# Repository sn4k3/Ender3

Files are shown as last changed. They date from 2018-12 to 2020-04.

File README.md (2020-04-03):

# Ender3
Supercharge your Ender3 with Guides, Mods and Addons.
Make your Ender3 work and worth like high end machines.

**Note:** I have spend many hours trying put this together so you can supercharge your Ender-3 for "Free", if my work is important to you or you fell this worth a tip i'm open to donations: https://www.paypal.me/SkillTournament

Discussion Groups:
* https://www.facebook.com/groups/Ender3/

## 1. PrusaSlicer

These profiles are based on a quality/speed balance (Universal).
Good prints without sacrifice the speed.
Make sure you have a good leveled printer and bed.

**NOTE:** Fine tune the start gcode for your printer! This is very important since i can't provide a all case profile for every modification and printer.

Modify at your needs.

### 1.1. Instalation
1. Download and install PrusaSlicer from: https://www.prusa3d.com/prusaslicer/
2. Start and configure PrusaSlicer (Wizard)
	* Choose Prusa MK3 and Creality Ender3 printers
	* Choose the filaments you want to apper (This can be latter done under Filament dropdown and select "Add/Remove Materials")
3. Close PrusaSlicer
4. On different operating systems open:
   * Windows: "%AppData%\PrusaSlicer\"
   * macOS: "/Users/[Username]/Library/Application Support/PrusaSlicer"
   * Linux: 
      * Stable build: "~/.PrusaSlicer/"
      * Alpha build: "~/.PrusaSlicer-alpha/"
5. Copy GitHub PrusaSlicer subfolders ("printer", "filament", "print") to the folder above
7. Open PrusaSlicer and check if profiles are there
8. To clean up interface remove profiles that you will not use: Printers you will not use (OPTIONAL)
9. Go under printer and use your current values for your printer, like max Z, limits, start gcodes or other things you may need to tune
10. Do a simple test print

## 2. Hardware

### 2.1. Best parts store:

* **Trianglelab:** https://trianglelab.aliexpress.com/store/1654223
* **Funssor:** https://www.aliexpress.com/store/115344

### 2.2. Recommended Hardware:

**Note:** Somes parts can override others! Study first what you want or need to buy.

* Cloned Bondtech BMG extruder for direct drive or better bowden: https://www.aliexpress.com/store/product/trianglelab-Bowden-Extruder-BMG-extruder-Cloned-Btech-Dual-Drive-Extruder-for-3d-printer-High-performance-for/1654223_329170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
* V6+Volcano 1.75mm 24V: https://www.aliexpress.com/store/product/Trianglelab-v6-Volcano-hotend-12V-24V-remote-Bowen-print-J-head-Hotend-and-cooling-fan-bracket/1654223_32844080369.html
* Volcano Nozzles (1.75 Full Size Kit): https://www.aliexpress.com/store/product/trianglelab-Top-quality-V6-volcano-Nozzle-for-3D-printers-hotend-5pcs-lot-volcano-upgrade-kit-for/1654223_32839344108.html
* Volcano Sock: https://www.aliexpress.com/item/Funssor-1pcs-Volcano-Heater-Block-Silicone-Socks-PT100-cartridge-Type-Silicone-Insulation-Sock-SILICONE-HEATER-BLOCK/32841090475.html
* Extruder gear: https://www.aliexpress.com/store/product/trianglelab-Drivegear-kit-dual-drive-gear-extruder-kit-Cloned-Btech-upgrade-for-Prusa-i3-3d-printer/1654223_32904209624.html
* MK8 Metal Extruder: https://www.aliexpress.com/item/Upgrade-3D-Printer-Parts-MK8-Extruder-Aluminum-Alloy-Block-bowden-extruder-1-75mm-Filament-for-creality/32834380573.html
* 3D Touch: https://www.aliexpress.com/store/product/Trianglelab-2018-NEW-3D-Printer-3D-TOUCH-SENSOR-Free-Shipping-Auto-BED-Leveling-Sensor-for-anet/1654223_32840691571.html
* BLTouch board adaptor: https://www.ebay.co.uk/itm/CR-10-Ender-3-Pin-27-Board-for-BL-Touch-Autobed-Levelling-or-filament-sensor/173475394925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
* TL Smoother Plus: https://www.aliexpress.com/store/product/Trianglelab-4-pieces-pack-TL-smoother-PLUS-addon-module-for-3D-pinter-motor-drivers-motor-Driver/1654223_32841473812.html
* NEMA 17 Dampers: https://www.aliexpress.com/item/Funssor-12pcs-lot-NEMA-17-Steel-Rubber-Stepper-Motor-Vibration-Dampers-Imported-genuine-42-stepper-motor/32825669027.html
* Official Glass Bed Surface: https://www.aliexpress.com/item/Newest-Creality-3D-Printer-Ender-3-Black-Carbon-Silicon-Crystal-Glass-Platform-Build-Hotbed-Glass-Platform/32890715441.html
* Bed Springs (4x): https://www.aliexpress.com/item/4-pcs-CREALITY-3D-Printer-Parts-Spring-For-Heated-bed-CR-10-CR-10Mini-CR-10S/32864621140.html
* Bed Isolator (300x300): https://www.aliexpress.com/item/3D-Printer-Part-Heated-Bed-Thermal-Insulator-Cotton-Heat-Insulation-Mat-for-Heatbed-Aluminum-Pad-PCB/32879628172.html
* 5015 24v Fan: https://www.aliexpress.com/item/2PCS-Gdstime-2-Pin-Ball-Bearing-DC-24V-Brushless-Cooling-Turbine-Blower-Fan-5015/32841967974.html
* 4010 24v Fan: https://www.aliexpress.com/item/2Pcs-DC-24V-40mm-x-40mm-x-10mm-2-Pin-Ball-Bearing-Computer-PC-Case-Silent/32727867521.html
* Fan speed controler: https://www.aliexpress.com/item/10pcs-lot-PWM-DC-6V-12V-24V-28V-3A-Motor-Speed-Control-New-Switch-Controller-1203B/32714571858.html
* Extreme v wheels (16x): https://www.aliexpress.com/item/High-precision-CNC-clear-Polycarbonate-Xtreme-v-wheel-kits-for-Openbuilds-v-slot-linear-rail-system/32849105844.html
* Belt Tensioner: https://www.aliexpress.com/store/product/Funssor-upgrade-Aluminum-alloy-Tornado-CR-10S-X-Axis-Tensioner-kit-For-Creality-cr-10-Ender/115344_32882354827.html
* XT30 Connectors: https://www.aliexpress.com/item/10pcs-Amass-XT30-Male-Female-Bullet-Connector-Plug-For-RC-FPV-Lipo-Battery-RC-Quadcopter-5/32784217001.html
* Arduino Uno for Stock motherboard bootloader burn: https://www.aliexpress.com/item/high-quality-One-set-UNO-R3-CH340G-MEGA328P-for-Arduino-UNO-R3-NO-USB-CABLE/32697443734.html
* Raspberry Pi 3+ with Octoprint and PiCamera

## 3. Printed Parts

### 3.1. Colections

* **sn4k3** https://www.thingiverse.com/sn4k3/collections/creality-ender-3
* **Nerys** https://www.thingiverse.com/Nerys/collections/ender-3

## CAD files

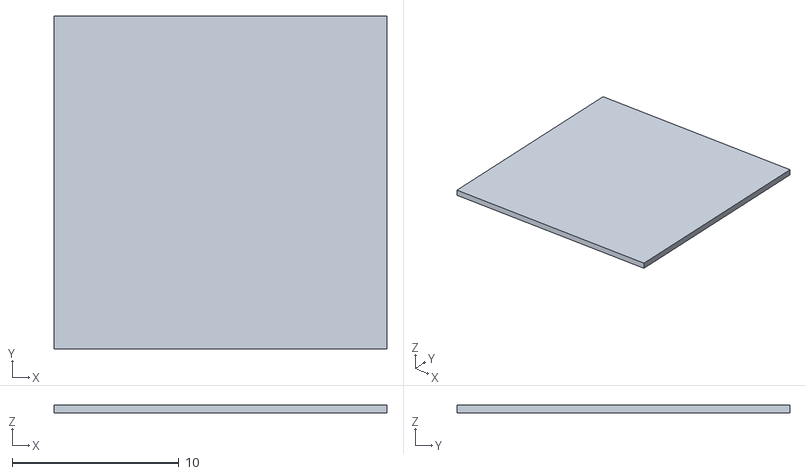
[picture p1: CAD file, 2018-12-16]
TestSTLs/2Layer20x203um.stl
20.0 x 20.0 x 0.5

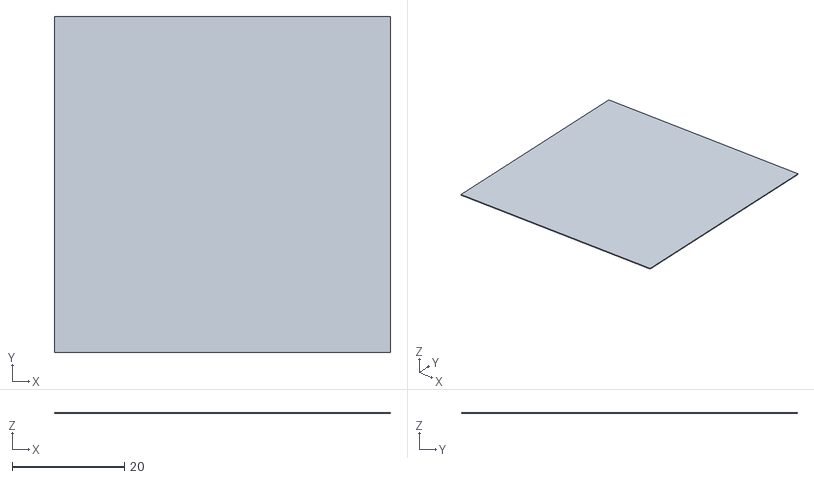
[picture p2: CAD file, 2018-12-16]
TestSTLs/1Layer60x60.stl
60.0 x 60.0 x 0.2

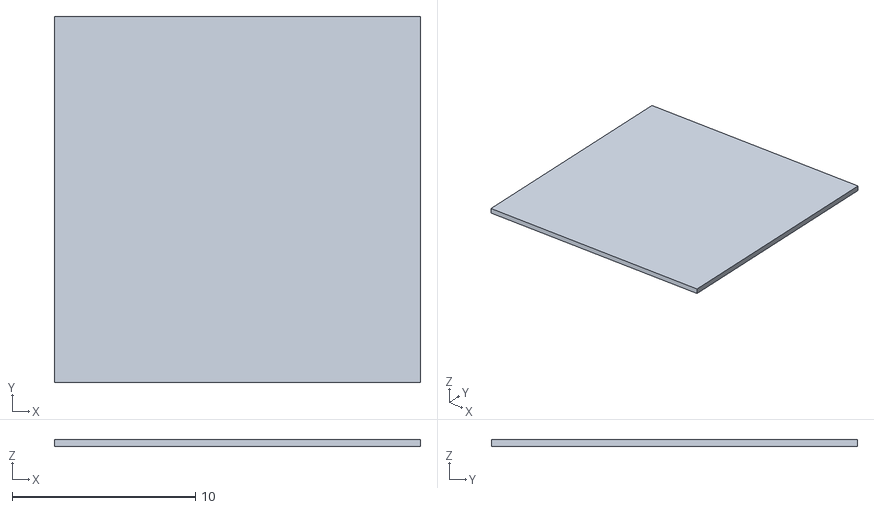
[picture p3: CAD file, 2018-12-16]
TestSTLs/2Layer20x20.stl
20.0 x 20.0 x 0.4

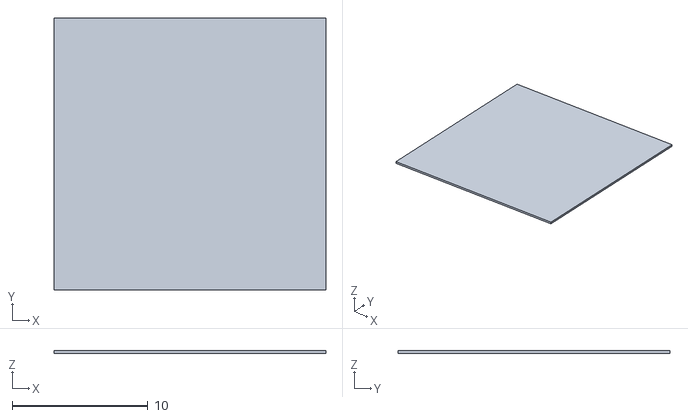
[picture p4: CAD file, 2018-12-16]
TestSTLs/1Layer20x20.stl
20.0 x 20.0 x 0.2

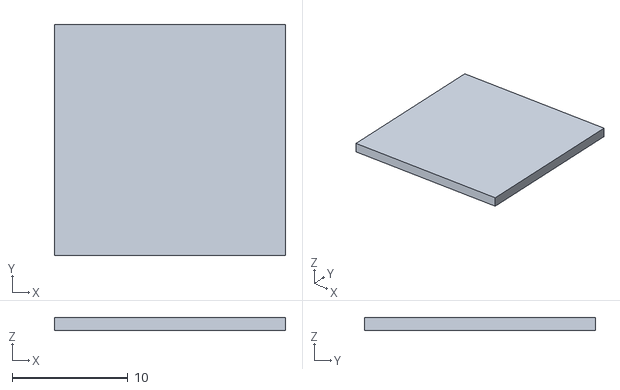
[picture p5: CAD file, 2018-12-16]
TestSTLs/6Layer20x20.stl
20.0 x 20.0 x 1.10

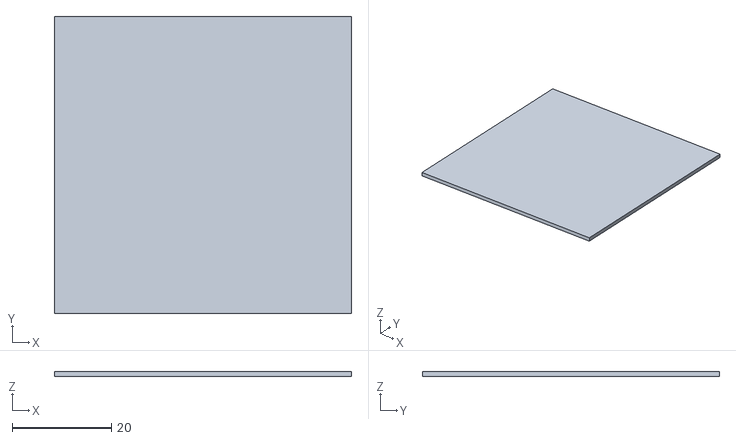
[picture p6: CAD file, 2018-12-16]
TestSTLs/6Layer60x60.stl
60.0 x 60.0 x 1.10

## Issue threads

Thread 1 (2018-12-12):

Error exporting gcode

XabierV, 2018-12-12:
Using printer Creality Ender3 - Stock, filament Generic PLA, and print 0.20mm Normal Ender3 with Slic3rPE 1.39.0, with 3DBenchy STL. Slice process completes correctly, but fails to export the gcode file, with the following error message:

!!!!! Failed to process the custom G-code template end_gcode
Parsing error at line 9: Not a variable name
{if layer_z < max_print_height}G1 Z{z_offset+min(layer_z+30, max_print_height)}{endif} ; Move print head up
    ^
!!!!! End of an error report for the custom G-code template end_gcode

I'm a total newbie with 3D printing and slicing, but it looks as the variable layer_z is not being initialized...

[3DBenchy_PLA0.2mm.gcode.txt](https://github.com/sn4k3/Ender3/files/2673063/3DBenchy_PLA0.2mm.gcode.txt)

sn4k3, 2018-12-12:
You need to download the new Slic3r PE, the 1.39 don't have that option... Please update

Closed 2018-12-12.

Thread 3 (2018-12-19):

Compatible printer strings?

talldonkey, 2018-12-19:
Hi - Thank you for keeping this up to date.

I was curious about your latest commit so I took a look at the diff and noticed that there's some mentions of Prusa where I think creality and ender 3 was intended, see below examples.

`compatible_printers_condition = printer_notes=~/.*PRINTER_VENDOR_PRUSA3D.*/ and printer_notes=~/.*PRINTER_MODEL_MK3.*/ and printer_notes=~/.*PRINTER_HAS_VOLCANO.*/ and nozzle_diameter[0]==0.6`

When I was expecting to see Creality instead of Prusa.  The *theoretical* effect would that these profiles would not show up when the Ender-3 is selected (I haven't tested it out for myself)

`compatible_printers_condition = printer_notes=~/.*PRINTER_VENDOR_CREALITY.*/ and printer_notes=~/.*PRINTER_MODEL_ENDER3.*/ and nozzle_diameter[0]==0.8 and printer_notes=~/.*PRINTER_HAS_VOLCANO.*/
`
I see this in mostly the new 0.6 nozzle files.

Was this intentional, (maybe I'm misunderstanding the reason why Prusa is in there)

sn4k3, 2018-12-19:
Hello,

The reason why i put that is because i have i have both MK3 and Ender 3 with same config (Direct Drive + Volcano + E3D) So to avoid edit two times the profiles i had put that to allow me share the profile on MK3 and Ender3, if you look at printer (Creality DD) you can find that:

Don't remove the following keywords! These keywords are used in the "compatible printer" condition of the print and filament profiles to link the particular print and filament profiles to this printer profile.
PRINTER_VENDOR_CREALITY
PRINTER_MODEL_ENDER3
PRINTER_HAS_VOLCANO
PRINTER_HAS_DIRECT_DRIVE
PRINTER_VENDOR_PRUSA3D
PRINTER_MODEL_MK3
MAX_VOLUMETRIC_25
MAX_SPEED_85

So in end is just to easy my life, and yes if you have Prusa MK3 you can use that too.
To convert in bowden you just need to change Printer Tab config.

Also i can't support every possible config, so take one and modify at your will, my start gcode would not work very well for the commun pleople since i have tons of mods include linear rails, so never forget to test and adjust printer tab!! All settings i have are tested by me when i use printer in that configuration.

Regards

talldonkey, 2018-12-21:
Hi, Ah - now that make sense now.  Great.  I also happen to have a MK3 Also
so this repo would be even more useful now!

Another question - you have BLTouch, and BLTouch Recall.  What's the Recall
version for?  I don't have a Bltouch but an EZABL, and would need to modify
the start codes, but wondering what it is - googling for "BLTouch Recall"
doesn't help much

On Tue, Dec 18, 2018 at 5:35 PM Tiago Conceição <notifications@github.com>
wrote:

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

sn4k3, 2018-12-21:
Yes recall is a name i gave myself, mean it will not run mesh bed but load it from last run values stored on EEPROM instead, so it's Recall ^^ and saves time, but last values must be there and ok (bed same level).
It work will ABL too but i recommend to run every time since ABL is faster than bltouch to probe i think...

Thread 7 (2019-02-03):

ColorMe3D PETG settings

NovaViper, 2019-02-03:
Hey guys! I'm very new to Slic3r and I would like to know if you guys could create a profile for the ColorMe3D PETG filaments, such as the ones I currently have below:

https://www.amazon.com/gp/product/B07L5V9LP7/ref=ppx_yo_dt_b_asin_title_o03__o00_s00?ie=UTF8&psc=1

https://www.amazon.com/gp/product/B07LB6RXDR/ref=ppx_yo_dt_b_asin_title_o02__o00_s00?ie=UTF8&psc=1

I would really appreciate the addition :D

sn4k3, 2019-02-03:
Do a blind profile will be inaccurate. Best is try with the real thing.
They say Hotend 235 and BED TEMP at 30, PETG need more temperature to bed to stick well so i recommend you try higher value like GENERIC PETG profile or from 70 to 90ºc.
After do can do a temperature tower from 210 to 240ºc and see which is better.
With that you will have your profile correct.
PS: Duplicate PETG profile and fine tune it

Closed 2019-02-03.

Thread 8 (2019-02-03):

Intro priming line collides with paper clips

probonopd, 2019-02-03:
The intro priming line collides with where most people would normally put their paper clips for attaching the flexible plate that comes with the later revisions of the Ender 3.

Hence, the intro priming line should be moved e.g., to the side, where no paper clips are usually installed.

sn4k3, 2019-02-03:
The profiles provide a base for users, the start gcode must be tuned by the user itself, since Ender3 is heavy modded i can't provide every case-of-use profile. The prime line is based on stock Ender3 (without ultrabase). BTW i also have a custom base and i hate clips because of that and smaller area, so i use Kypton tape all arround +/- 5mm edge. Have hard objects under nozzle area is always a bad idea

sn4k3, 2019-02-04:
I can do that latter. But you can see my 0.6mm DD profile which have prime line that way and replace the gcode for your profile. You can also send a pull request with that mod

sn4k3, 2019-02-08:
Change prime to Y on new release

probonopd, 2019-02-08:
Thanks. :+1:

Closed 2019-02-08.

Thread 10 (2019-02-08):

Under extrusion on small cylinders with possible fix.

abrileroux, 2019-02-08:
Hi there,
First of all thank you very much for the profiles for the ender 3. I'm getting the best prints I've ever had with your profiles.

I ran into an issue where the whole print would work beautifully until I got to a small cylinder/chimney shape. The printer would under-extrude badly for that shape resulting in a failure. The same file would print fine when sliced with Cura.

[Pictures](https://imgur.com/a/LZ0PhBn)

The solution I found was to remove the following line from the start Gcode :

`M221 S{if layer_height<0.075}100{else}95{endif}`

It seems that the flow rate of 95 was just low enough to fail.
A flow rate of 100 doesn't cause any problems with the print, so I haven't noticed a downside to removing it (yet).

Just wanted to share my finding. Thank you again!

yarus23, 2019-02-08:
95 is too low for quality supports that are printed with higher speed. So 100% is the best value

sn4k3, 2019-02-08:
95 was the best value i found after tune e-steps. Are your e-steps extruding 100mm out of 100mm?
My ender3 come with esteps a bit off so i tunned first and 100% at slice gave me overextrusion, that's why i set it to 95.
Please tell me about your e-steps value

abrileroux, 2019-02-08:
> Please tell me about your e-steps value

Hi there, sure. My E-steps is at 100.4.

Thanks

sn4k3, 2019-02-08:
Humm a bit higher then my was. My was 98 for get perfect 100mm out of 100mm PLA

sn4k3, 2019-02-08:
Ajustment removed

Closed 2019-02-08.

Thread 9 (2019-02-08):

Adjust Z position

yarus23, 2019-02-08:
I have to insert
G28 Z
before G1 Z0.6 because we need to go home by Z axis before printing, otherwise it prints in the air

abrileroux, 2019-02-08:
Thanks for that - I also have this issue

sn4k3, 2019-02-08:
Confirmed, G28; missing before print starts, i will fix soon

sn4k3, 2019-02-08:
Fixed on new release

Closed 2019-02-08.

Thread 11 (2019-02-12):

Under/no extrusion while after priming phase

NovaViper, 2019-02-12:
For some strange reason, I notice that the printer doesn't seem to be extruding at all, which has been causing me **lots** of headache trying to figure out why.

sn4k3, 2019-02-12:
Which printer profile are you using?
Can you try manual extrusion via printer menu and see if it extrudes at all?

NovaViper, 2019-02-24:
I think it's my e-steps not being calibrated. I'm going to go and try to calibrate them sometime Friday and *hopefully* get the issue fixed

sn4k3, 2019-02-24:
I had that problem before and was e-steps

Closed 2019-02-24.

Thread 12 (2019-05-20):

Question: Does the jerky-zick-zack move work in practice?

talldonkey, 2019-05-20:
Hi, just wondering how useful you find the jerky zick zack move.  I notice that you have it commented out (or its not there) on some profiles, especially Ender-3 BLtouch printer profile.

G91 ; Use relative mode
; Make some jerky zick-zack move at the beginning
; This is supposed to get rid of residue at the nozzle
;G1 X1.0 Y5.0 Z-0.1 E-1.0 F7200 ; X6 Y10 Z0.1, retract a tiny bit / 120mm/s
;G1 X1.0 Y-5.0 Z0.1 E2.0 F7200 ; X7 Y5 Z0.2 extrude a tiny bit
;G1 X2.0 Y5.0 Z-0.1 F7200 ; X9 Y10 Z0.1
;G1 X2.0 Y-5.0 Z0.1 F7200 ; X11 Y5 Z0.2
;G1 X2.0 Y5.0 F7200 ; X13 Y10
;G1 X2.0 Y-5.0 F7200 ; X15 Y5

sn4k3, 2019-05-20:
Hello, It's disable on other for safety, if nozzle goes under bed it can crash and make damage somewhere.
It's not very usefull since it need be very close from bed, and i can't provide that on universal profiles.
The purge line is ok.
It would be more usefull if your printer had a cleaning zone with brushes or something to clean nozzle.

Closed 2019-05-24.

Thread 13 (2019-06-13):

Filament priming

sfjuocekr, 2019-06-13:
The feed rate during the priming strip is a little high.

The first part comes out okay, but during the second part the extruder gear slips and if your coupling like mine is a little wonkey it will slide out as it is the weakest link after the extruder gear.

Personally, I don't think overextruding with force is required to prime the nozzle.

sfjuocekr, 2019-06-13:
Also, the start gcode differs between the profiles. I think you forgot to update the others, for example stock still has the jerky zig zag!

sn4k3, 2019-06-13:
The printer tab must be configured to the user preference and needs.
What printer setting you are using?

sfjuocekr, 2019-06-18:
Ender-3

If you do a diff on the stock profile vs one of the recently changed ones and grep out the start gcode line you will notice the differences.

sn4k3, 2019-06-18:
You mean Ender3 Stock? I know stock are different from others in prime.
I don't have stock anymore to test and try, my bed is also different coordinates and size.
On installation change printer tab and tune to your preference is required and a step of instalation, i can't cover a all in one profile as ender3 is the most hacked printer. When i used the stock profile in the past my extruder never click or skip steps at prime.
But if you can fix it, test and send gcode back, i will update the default for stock and bltouch which have same prime

Closed 2019-07-13.

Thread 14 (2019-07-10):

this is not an issue.. just a question

phamre, 2019-07-10:
Hello..

i like your work.. thanks

i have direct drive setup with v6 hotend and bmg extruder..
u think i can use your volcano direct drive profile?
im not sure what differance between v6 and volcano hotend

Thanks again

sn4k3, 2019-07-10:
Sure you can use. Just go printer tab and remove volcano from comments. OR reduce max speeds by half at all infills

DAddYE, 2019-07-24:
What exact setup are you using? I’m same as OP but I’ve a 0.6 volcano nozzle. Can I use volcano profiles?

I’m also wondering if i change to a 0.4 nozzle should I change all values in the Extruder setting as well... right?

Lastly, what’s the difference with bl touch and the one with recall?

Thanks mate!

NovaViper, 2019-07-24:
@DAddYE The recall one basically is the same like the regular bltouch one with the exception that it loads the mesh data that you set before (and not probe the bed before each print) while the regular bltouch profile *always* probe the bed before starting the print

sn4k3, 2019-07-24:
> What exact setup are you using? I’m same as OP but I’ve a 0.6 volcano nozzle. Can I use volcano profiles?

I'm using 0.6mm Volcano DD (Direct Drive)
You can and should use it, but if you have bowden you need to change two parameters only (retraction is all you need to change in fact)

> I’m also wondering if i change to a 0.4 nozzle should I change all values in the Extruder setting as well... right?
>

If so you need to recreate profiles and printer, mostly you will only incrase infills speeds but only up to a safe margin which i set to be +/- 150mm/s

> Lastly, what’s the difference with bl touch and the one with recall?
>
> Thanks mate!

Already anwsered

DAddYE, 2019-07-25:
Thanks mate! I got this:

MK8 Bowden Extruder BMG extruder + V6 HOTEND Dual Drive Extruder for 3D Printer High Performance for I3 3D Printer - (Size: BMG 24V All-Metal) https://www.amazon.com/dp/B07KVHG5FH/ref=cm_sw_r_cp_api_i_nOsoDbTB4YVFN

I’m on direct drive but I have a v6 hot end.

phamre, 2019-07-29:
> Sure you can use. Just go printer tab and remove volcano from comments. OR reduce max speeds by half at all infills

i dont understand what comments i need to remove.. and when i change Directdrive profile and save with a new name.. all printer profiles so are not there longer..

maby you can take a screenshot and show what i need to do?

sn4k3, 2019-07-29:
@phamre tell me your setup (noozle size, volcano or v6, Bowden or direct, bed probe)

DAddYE, 2019-07-30:
The volcano option, AFAIK, only enables specific filament profiles.

Do the options in the notes do anything else?

sn4k3, 2019-07-30:
Notes are used to show/hide profiles and filaments based on volcano. Also used for linear pressure

phamre, 2019-07-30:
> @phamre tell me your setup (noozle size, volcano or v6, Bowden or direct, bed probe)

@sn4k3 My Setup: 0.4mm Noozle, v6 hotend(trianglelab) bmg extruder(trianglelab) Direct Drive, EZABL Probe

sn4k3, 2019-07-31:
ok do the following:

1) Duplicate Ender 3 stock + BLTouch
2) Go Notes and remove "PRINTER_HAS_BOWDEN"
3) Go extruder 1 and set Retraction Lenght to 0.8mm or your best value.
4) Done - Do print test

PS: I notice crazy accel values for stock due new slic3r version, will fix them and push them, please download new profiles from master

plazmax, 2019-07-31:
Ty sn4k3 i have simular trianglelab e3dv6, titan with pancake directdrive except abl i can do same with ender 3 stock , btw i installed prusa slicsr 2.0 too but slicer pe works better with ur setting cant wait new update thank you

sn4k3, 2019-07-31:
Master updated

phamre, 2019-07-31:
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

Thanks i will do a test now. but i forgot to say im using Linear Advance

sn4k3, 2019-07-31:
Ok then you need to define the K for each filament. Add a printer note like: PRINTER_FULLMODEL_ENDER3_DD_04
After go filament tab under "Custom G-Code" define your K and use your PRINTER_FULLMODEL_ENDER3_DD_04, example:

M900 K{if printer_notes=~/.*PRINTER_VENDOR_PRUSA3D.*/ and printer_notes=~/.*PRINTER_HAS_BOWDEN.*/}200{elsif printer_notes=~/.*PRINTER_VENDOR_PRUSA3D.*/ and nozzle_diameter[0]==0.6}15{elsif printer_notes=~/.*PRINTER_VENDOR_PRUSA3D.*/ and nozzle_diameter[0]==0.4}30{elsif printer_notes=~/.*PRINTER_FULLMODEL_ENDER3_DD_06.*/}0.04{elsif printer_notes=~/.*PRINTER_FULLMODEL_ENDER3_DD_04.*/}0.04{else}0{endif} ; Filament gcode

phamre, 2019-08-03:
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

ok. im not sure i understand.. what i need to add to notes in printer tab and filament tab? for  my filament Kfactor is 0.15

sn4k3, 2019-08-03:
Not right... If you use only one printer you can ignore that all ifs and notes. That's only usefull when you use multiple printers. So you can set M900 K0.15 alone instead all that mess.

phamre, 2019-08-03:
> Not right... If you use only one printer you can ignore that all ifs and notes. That's only usefull when you use multiple printers. So you can set M900 K0.15 alone instead all that mess.

only M900 K0.15 under Filament Tab -> Custom G-code ?

sn4k3, 2019-08-03:
Exactly

Closed 2019-07-13.

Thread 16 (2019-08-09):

Infilll and Solid Infill and Max speeds for 0.2 print profile (stock) is way too high for certain filaments

NovaViper, 2019-08-09:
Hi there! I wanted to report an issue relating with the Infill/Solid Infill and Max speeds for the stock 0.2 print normal profile. For some odd reason, they're set REALLY high (80 for the infills and 90 for the max speed to be extact) while every other profile is set between 50-71. For certain filaments (PETG in my case) this is *way* too fast for the infill to handle and it will immediately get ripped off the model and make basically large gashes in the model (which inventibly causes print failures).

Currently, I've set those settings all to 56 and that seemed to have fix my troubles. I haven't tried out the high speed on PLA but it's definitely way too much for PETG to handle

sn4k3, 2019-08-09:
Hello, Speeds are based on MVS, for 0.2mm profile the 80mm/s seens ok for normal PETG (80*0,2*0,45
= 7,2mm^3/s) While PETG is cap at 8mm^3/s on filament tab, so is under the PETG limit.
Now it can depend on temperature and filament you using, can you post your filament brand/name and temperatures you using? Also the motor and gear can influence max MVS.

Instead of mess with speed which affect all other filaments, you can clone PETG filament and set "Max Volumetric Speed" to a lower value, and speed will ajust according.

NovaViper, 2019-08-11:
I tried with ColorMe3D Blacker Black and Haze Purple, and Amazon Basics Purple. All running at 235C for the hotend and 75C for the bed

sn4k3, 2019-08-11:
That's strange, 56mm/s seens low for infills given that profile, i renember i had no problem with Prusa PET when i have stock, now i can't test anymore since no longet stock.
Do you have lastest master profile? Because i updated machine limits which were in crazy numbers

NovaViper, 2019-08-11:
Oh! So it seems I do have an older version of the master profile. I'm updating my settings now :)

sn4k3, 2019-08-11:
> Oh! So it seems I do have an older version of the master profile. I'm updating my settings now :)

Update it and report back

NovaViper, 2019-08-12:
I just got new profile settings added and I did decrease the volumetic speed to 7, though I still have some blobbing.. I'm going to go and switch out my nozzle (I have a 0.5 nozzle installed) and see if that's what is causing the issue

sn4k3, 2019-08-12:
Wait you have 0.5mm nozzle in but using the 0.4 profiles?

NovaViper, 2019-08-12:
Yeah, I had to restort to switching it because I kept having issues printing 0.32 layer heights with my 0.4 nozzle

sn4k3, 2019-08-12:
You can't use 0.4mm profiles with a 0.5mm nozzle, there are change that must be done, including on printer tab...

but 0.4mm nozzle can do 0.32mm layers, the problem you have maybe related to other thing (If speed down doesnt help)

NovaViper, 2019-08-13:
For some reason after that first layer, it started failing again once I went back to my 0.4 nozzle. The filament settings was all stock (except for my temps) .-.

NovaViper, 2019-08-13:
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

sn4k3, 2019-08-13:
Look likes more a height problem than speed. Does your extruder click?
Try put 5 at volumetric speed under filament tab

sn4k3, 2019-08-13:
Use 40x40 square tests to speed up tests

NovaViper, 2019-08-13:
I didn't hear the extruder clicking, and whenever it prints perimeters and walls, it doesn't have the issue shown. Im currently releveling the bed just in case it's off from my last print in PLA

NovaViper, 2019-08-13:
Ok.. so I got a 50x50x1.28 mm rectangle going.. and it seems to be much better at 5mm^3/s

sn4k3, 2019-08-13:
IF better but not perfect try lower, like 4

NovaViper, 2019-08-13:
Welp, it did this in the end
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

NovaViper, 2019-08-13:
But all the other layers were fine (but I didn't catch the final or the one before it to thoroughly confirm it)

NovaViper, 2019-08-13:
I can confirm that it did indeed do that in the very top layer
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

NovaViper, 2019-08-13:
There was some issues in the layer right under it to.. it looks like at one particular spot it didn't stick properly
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

NovaViper, 2019-08-13:
*Sigh* The 4mm^3/s top layer had issues, no layer had issues
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

sn4k3, 2019-08-13:
Well set MVS to 1 (lower than TPU xD) if you still have problem is not related to speed.

NovaViper, 2019-08-13:
Should I turn off the cooling fan entirely? The cooling fan seems to kick on at the very last layer

sn4k3, 2019-08-13:
> Should I turn off the cooling fan entirely? The cooling fan seems to kick on at the very last layer

You can try, but i guess not the fan causing the problem

NovaViper, 2019-08-13:
I just started the print at 1VMS and no fan for the PETG. I'll try the PLA one afterward

NovaViper, 2019-08-13:
This time at 1 MVS and the fan off,it came out *perfect*

sn4k3, 2019-08-13:
If MVS value is respected that mean +/- 7mm/s speed. Can you confirm that is that slow?
Now you can reenable fan as it was

NovaViper, 2019-08-13:
It came out *really* slow.. took an entire hour to finish the print instead of 15 minutes

NovaViper, 2019-08-13:
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

sn4k3, 2019-08-13:
Can you try now with PLA?

NovaViper, 2019-08-13:
Alrighty. im starting the PLA print now

NovaViper, 2019-08-13:
The PLA one came out perfectly too, I'm using all the stock settings in the Generic PLA profile

sn4k3, 2019-08-13:
With stock speeds right?
Then something is wrong with filament, do you have other pet brand? Humidity can ruin a spool

NovaViper, 2019-08-14:
I do have other brands, but they all have had the same issue

sn4k3, 2019-08-14:
Well if problem presists on PET the best bet is test the max MVS your printer steup support. a good way to set that is print with stock profiles. At second layer when problem comes start slowing down the printer speed using the knob (FR) up you see a good line pattern. Then look at FR percentage, lets say it's 75%. Pick stock MVS and multiply by 0.75, eg: 8*0.75 = 6
Thats the way i pick the real max speeds, but again, max everything is not a general rule for everyone, a better extruder can extrude more, depend on each one setup

NovaViper, 2019-08-14:
Ya think I should also use completely stock filament settings from the Generic PET profile?

sn4k3, 2019-08-14:
To get your limit yes, and when found create or modify the profile with your value

NovaViper, 2019-08-14:
I just noticed that the infills are *really* high
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

NovaViper, 2019-08-14:
It's not ripping up layers but it still looks a bit rough
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

sn4k3, 2019-08-14:
> I just noticed that the infills are _really_ high with all stock settings

All settings print at same MVS on infills, speed is a illusion, printing at 40mm/s can be slower than a 20mm/s on other setup, what matter is the Volumetric speed (MVS). So all profiles are boosting infill and solid infill to max. capability. Top and bottom infill are always slower to get a better finish.

Find your best infill speed and use that as reference

NovaViper, 2019-08-14:
Just finished the stock settings print and it got better when I slowed it down to 70%,  but then for some reason the top infill got blobs in it

NovaViper, 2019-08-14:
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

sn4k3, 2019-08-14:
> Just finished the stock settings print and it got better when I slowed it down to 70%, but then for some reason the top infill got blobs in it

Try 60%, then 50% keep testing up to get the perfect look

sn4k3, 2019-08-14:
What mods you have on your printer? Complete setup? As i see is not stock stock

NovaViper, 2019-08-14:
The bed is just a plain glass pane I got from Home Depot coated with sugar water, the hotend is actually still the same, except I have mounted my extruder to be directly ontop of the hotend (hence it's direct drive now) and the fan shroud is the Petsfang Bullseye

sn4k3, 2019-08-14:
Ok then you should calibrate your extruder.
Mark 20cm with a pen on filament, using terminal or LCD extrude 100mm. When it stop check if mark hit at 10cm on the ruller. If no you need calibrate your e-steps.
Also as you have direct drive how much retraction you set on extruder?

NovaViper, 2019-08-14:
I used to have 1.8mm and 70mm/s for the retraction; when doing the tests, I started using 0.8mm and 35mm/s

NovaViper, 2019-08-14:
Also how do I calibrate e steps on a direct drive extruder?

sn4k3, 2019-08-14:
> I used to have 1.8mm and 70mm/s for the retraction; when doing the tests, I started using 0.8mm and 35mm/s

Thats seens ok as start point.

> Also how do I calibrate e steps on a direct drive extruder?

With the method i said before, marking, extruding and verify extruded lenght

NovaViper, 2019-08-15:
The e steps are fine, I marked 120 and told to extrude 100, and 100mm got extruded

sn4k3, 2019-08-15:
Ok, one more check: with steppers enabled (Holding) try to pull fillament by hand to see if gear rotate, it shall not rotate. If filament gets out mean gear grub is lose

NovaViper, 2019-08-15:
I can't get it to budge at all

sn4k3, 2019-08-15:
> I can't get it to budge at all

Well i'm out of possibilities, i guess you have to decrease speed for PET go with it.
As last check, go slicer and see if nozzle size is correctly set, as extrusions width on advanced (should be 0.45mm)

NovaViper, 2019-08-15:
Welp! I just I may have discovered what our culprit is! So the weather in my area has been going nuts lately (with it being abnormally hot and because it's Louisiana, the humidity is quite high) and my main air conditioning unit breaking due to the extreme heat, the humidity in the air must have gotten high enough to actually affect the prints. So I went today and let my window air unit run for the majority of the day. I just ran the print and the layers came out perfectly

sn4k3, 2019-08-15:
Humidity ruin pet spools, if you have that issue better build a spools dehumidifier. Or cook it at 50°c for day

NovaViper, 2019-08-15:
Ok I think my PETG doesn't like the new temp settings, mid way in printing out this case, I notice this MASSIVE clump of filament stuck on the nozzle and it literally jacked the entire print up

NovaViper, 2019-08-15:
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

Zviki68, 2019-08-25:
What's your nozzle temperature?

NovaViper, 2019-08-25:
> What's your nozzle temperature? And what slicer you are using?

240 and Prusa Slicer, I'm using all of the stock filament profile settings that's for the Generic PETG filament

NovaViper, 2020-01-11:
Hey im going to close this! I switched to a TriangleLabs V6 and my printer's being doing really well with the infills and PETG! Thanks for making the profile!

sn4k3, 2020-01-11:
Most likely a extruder problem before.

NovaViper, 2020-01-11:
@sn4k3 The oddest thing is that im actually still using the stock extruder, and the printer prints perfectly now with PETG, haven't experienced the same issue since switching

sn4k3, 2020-01-11:
Some bad tune, better this way

Closed 2020-01-11.

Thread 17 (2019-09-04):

Slicing with these profiles is very slow!

marksu78, 2019-09-04:
Slicing with these profiles takes a long time! PrusaSlicer 2.0.0 does the basic slicing quickly but then the "Generating G-Code" can take minutes.

When I slice the same STL with built in Prusa profiles it takes just few seconds!

As an example:
https://www.thingiverse.com/thing:3576952

To slice this with the unmodified settings of:
**Printer**: Creality Ender-3 Stock
**Filament**: Generic PLA
**Print settings**: 0,20mm NORMAL Ender3

The initial slicing takes **7 seconds**, Generating G-Code takes **3min 53 seconds**

Now if I change the settings to:
**Printer**: Original Prusa i3 MK3S
**Filament**: Prusament PLA
**Print settings**: 0.2mm QUALITY MK3

The whole slicing and G-Code generation is done in **10 seconds!**

A huge difference! What might be the reason why the slicing takes so much longer time with these profiles?

sn4k3, 2019-09-04:
Hello, disable avoid crossing perimeters. It's what causing the delay. The bigger the model the more it will take with that option

marksu78, 2019-09-04:
Yes, that helped thank you! I need to do some experimenting how much that feature actually helps, so if it's worth the extra time on bigger models

sn4k3, 2019-09-04:
That's only usefull for Bowden to avoid cross perimeters and then retracts, that's it. If your retracts make no mess or trouble you can put that off

marksu78, 2019-09-04:
Yes, I have now disabled it from all the print settings. I will enable it again if prints get messy with certain materials and then see if it helps.

Closed 2019-09-04.

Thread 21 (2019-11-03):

Insane high acceleration

Laess3r, 2019-11-03:
Hy!
Why is the acceleration set to 9000mm/sec? The ender 3 default is 500mm/s ;-)
My prints suffer from ringing in both x and y axis with this profile.

Best regards

sn4k3, 2019-11-03:
You using Ender3 stock?
Check if you have last commit, that was fixed some commits ago

Laess3r, 2019-11-03:
Hy! Thanks for you reply! Yes, Stock Ender 3 Printer profile.
You are right, in your current version the accel values seem to be much better! Thank you :-)

sn4k3, 2019-11-03:
Good, check repository from time a time. I may commit new improvements.

Closed 2019-11-03.

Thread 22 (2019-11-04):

Filament yanked off bed when travelling on first layer

diabl0w, 2019-11-04:
First of all, thank you for these profiles! They are amazing, except this one major problem I am having:

I am having an issue with the ender 3 0.24 FAST print profile where after the initial line that is printed across the bed in front from left to right, as soon as it finishes at the right side and goes to travel toward the center to begin the actual print, it yanks/pulls/curls up the last 10mm or so of filament off the bed with it. This also happens for basically any movement on the first layer of the print where it prints a line or perimeter and then stops to travel somewhere else on the bed. Then the loose ends sticking in the air get bumped into and everything is a mess.

Can you recommend which settings I can add/change to fix this?

sn4k3, 2019-11-04:
Can you post a video?
What mods you have on your printer?
Do you change any settings on slicer?

diabl0w, 2019-11-04:
Solved by installing the latest version of slicer... I apologize, I should have tested that before opening an issue. Thanks for the reply!

Closed 2019-11-04.

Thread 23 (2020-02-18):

Compatibility/Implementation with New Ender Profile in 2.2.0 alpha

Astrofreak85, 2020-02-18:
Your profiles are good, the new Ender3 profiles in 2.2.0 alpha are a bit slower than yours and they don't have as many profiles as you.
You may ask if they can implement your profiles out of the box?

sn4k3, 2020-02-18:
They are still in alpha, let it get stable first. They will priority quality at a usable speed. My profiles push the machine a little bit and offer thicker extrusion selection to boost print speed. They support some nozzles but not volcano so far even for mk3. You can always use my profiles in pair with prusa, is not a problem, i guess they will not collide with names

NovaViper, 2020-02-18:
> Your profiles are good, the new Ender3 profiles in 2.2.0 alpha are a bit slower than yours and they don't have as many profiles as you.
> You may ask if they can implement your profiles out of the box?

The profile as it is now works with the alpha 2.2.0

Closed 2020-02-18.

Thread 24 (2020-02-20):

Invalid and Unknown commands in klipper

seebaer1976, 2020-02-20:
Hi
I use "Klipper" as firmware because I have a few invalid and unknown commands in klipper.

Invalid M204 command "N5 M204 T1250*82"
Unknown command:"M900"
Unknown command:"M280"

One parameter seems to be missing from the M204.
M900 and M280 are not supported by Klipper.

M900 is used differently on Klipper.
https://github.com/KevinOConnor/klipper/issues/92

NovaViper, 2020-02-20:
@seebaer1976 The profiles were made for Marlin firmware, not Klipper. You should be able to change the gcode to work with Klipper

sn4k3, 2020-02-20:
Ignore that errors, it will continue to print. M900 and M204 are configured in klipper config file and will not hurt leave them on gcode since they will no nothing.
As for M280 is bltouch related, it may have other command to klipper that you need to look for.

seebaer1976, 2020-02-20:
After reading back and forth for a long time and your help, I was able to solve it.

@sn4k3 sn4k3 M900 and M204 = pressure_advance, you had it in your config but I didn't have it in mine. commented out the two commands in the PrusaSlicer.
I could also solve M280, simply create a macro in the Klipper config:

[gcode_macro M280 P0 S160]
gcode:
BLTOUCH_DEBUG COMMAND = reset

Thank you for your help.

sn4k3, 2020-02-20:
Glad you fix it. Regards

seebaer1976, 2020-02-20:
then it can be closed

darkstudio, 2022-09-03:
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

Hi, when we create a macro with "SPACE" , Klipper refuse to restart firmware and show a error message =>

_**Name of section 'gcode_macro M280 P0 S160' contains illegal whitespace

Once the underlying issue is corrected, use the "RESTART"
command to reload the config and restart the host software.
Printer is halted**_

Space is not supported

Closed 2020-02-20.

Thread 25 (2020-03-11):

Problems encountered with your config

superm1, 2020-03-11:
Hi,

I've recently tried switching to Prusa using your set of configs from Cura.  Overall I really love them, but I noticed two things I wanted to mention.

1. I don't seem to get good adhesion by default on my glass bed, even with your temperatures set.  I bumped up "disable fan for the first" to 4 layers, and this seems to help me.  Wondering why you picked one by default?  (Prusa default seems to be 3).

2. At the end of a tall but wide print I found the head came crashing down on the print when it reset since it resets to left and then back down to 0 Z height.  Cura's default was resetting to a higher Z and this never happened.

I compared cura's code and yours and it seems that for Cura they just reset to raise Z:
```
G1 Z10 ;Raise Z more
```

With yours I see it's an if statement.  Since I've been seeing it reset to effectively zero every time for me I have to wonder if one of those variables isn't working right as end G code.
```
{if layer_z < max_print_height}G1 Z{z_offset+min(layer_z+30, max_print_height)}{endif} ; Move print head up
```

I double checked my octoprint log and this is what it sent:
```
G1 Z77.6*66
```

superm1, 2020-03-11:
Full set of last commands:
```
Send: N39210 G90*25
Recv: ok
Send: N39211 G1 Z77.6*66
Recv:  T:209.92 /0.00 B:60.36 /0.00 @:83 B@:0
Recv: ok
Send: N39212 G28 X0*80
Recv:  T:209.88 /0.00 B:60.19 /0.00 @:0 B@:0
Recv: echo:busy: processing
Recv: X:0.00 Y:137.30 Z:77.51 E:24358.85 Count X:0 Y:10984 Z:31006
Recv: ok
Send: N39213 G1 Y180*98
Recv: ok
Send: N39214 M84*18
```

superm1, 2020-03-11:
Hmm, experimenting some it seems that sending the G1 Y180 is actually what's doing it which makes no sense..

sn4k3, 2020-03-12:
Hello,
Glass beds are not the best in adhesion without additives, i never used glass and i rarely have adhesion problems. Profiles are also based on stock which have a very strong adhesion.
You also have to make sure the bed temperature is stable and there are no air drafs (AC, doors open, air moving) Some brands of PLA are better than others on adhesion, you can try incrase 5ºc to bed temperature if having problems.

About reset, what mods do you have on printer? Any PowerResume or backup mod?

superm1, 2020-03-12:
Thanks for responding.

>Glass beds are not the best in adhesion without additives, i never used glass and i rarely have adhesion problems. Profiles are also based on stock which have a very strong adhesion.
You also have to make sure the bed temperature is stable and there are no air drafs (AC, doors open, air moving) Some brands of PLA are better than others on adhesion, you can try increase 5ºc-10ºc to bed temperature if having problems.

I've tried hatchbox and Amazon basics brands PLA and encountered this with both even after raising the temperature some.  The only thing that has helped so far for me was increasing number of layers before fan turned on. I did previously have a magnetic bed, but it got trashed from bending while removing prints and/or printing PETG on it.  The glass bed I have does have a black coating on the top though.

>About reset, what mods do you have on printer? Any PowerResume or backup mod?
Using last version of PrusaSlicer?

Only mods have been BLTouch and newer springs.  Otherwise stock ender-3 pro.  I used the BLTouch FW from creality's website, haven't yet tried to move to a newer version of merlin or anything like that.
Using Prusa 2.2.0-rc2.

I have reproduced it just by resending that set of reset commands I captured from octoprint's terminal too now, so I think that at least rules out prusa causing it.

sn4k3, 2020-03-12:
`I've tried hatchbox and Amazon basics brands PLA and encountered this with both even after raising the temperature some. The only thing that has helped so far for me was increasing number of layers before fan turned on.`

If the increased layers without fan works well for you then there are no bad to keep that settings. Pleople often use a layer of glue to glass to prevent warping, cura seens to squish more one first layer than slicer.

`I have reproduced it just by resending that set of reset commands I captured from octoprint's terminal too now, so I think that at least rules out prusa causing it.`

I'm always at stable releases, can you try with the stable PE? Anyway i will try that latter on my E3. Just print something and cut power then turn on again to reproduce the problem?

superm1, 2020-03-13:
>If the increased layers without fan works well for you then there are no bad to keep that settings. It can only impact very small models. Pleople often use a layer of glue to glass to prevent warping, cura seens to squish more one first layer than slicer.

Yeah I tried to print a tree model and some of the leaves started to warp; I think you're right "small models" still don't adhere well to the glass.

>I'm always at stable releases, can you try with the stable PE? Anyway i will try that latter on my E3. Just print something and cut power then turn on again to reproduce the problem?

Yeah I just finished a print done with prusa and your config, cut the printers power and then from Octoprint sent the following:
```
G90
G1 Z77.6
G28 X0
G1 Y180

```

On the G1 Y180 the Z axis reset too.

sn4k3, 2020-03-13:
>Yeah I tried to print a tree model and some of the leaves started to warp; I think you're right "small models" still don't adhere well to the glass.

Put a layer of glue stick, it will last many prints and easy to clean/mantain, that way is trouble free

> Yeah I just finished a print done with prusa and your config, cut the printers power and then from Octoprint sent the following:

I tried to reproduce the problem using your steps, my print does exactly what gcodes does and Z stay on same level untouched. I'm using last marlin bugfix but in all my versions it never happen to me, in fact on a power reset the end gcode always raized Z not lowered. If you sending G1 Yxxx it should move Y not Z, why printer thinks your Y is Z? Do you double check your configurations and wiring?

superm1, 2020-03-13:
> I tried to reproduce the problem using your steps, my print does exactly what gcodes does and Z stay on same level untouched.

Yeah that's the exact behavior that I expected too..

> I'm using last marlin bugfix but in all my versions it never happen to me, in fact on a power reset the end gcode always raized Z not lowered.

When you flashed last marlin bugfix release, any modifications needed?  Just put a bootloader on and then load new FW from Octoprint?  Sorry this part is new to me, but I think I can easily put a bootloader in place using the ISP that came with BLTouch.

>If you sending G1 Yxxx it should move Y not Z, why printer thinks your Y is Z? Do you double check your configurations and wiring?

I didn't touch the wiring from what was factory other than adding BLtouch.
Normally Y and Z commands work.  If Y and Z were swapped I would sure be getting some funky prints at least :)
So I have to think there is a bug in the FW build loaded on the printer related to this set of circumstances where the heads are or something.  Your commands seem sound to me.

sn4k3, 2020-03-13:
> When you flashed last marlin bugfix release, any modifications needed? Just put a bootloader on and then load new FW from Octoprint? Sorry this part is new to me, but I think I can easily put a bootloader in place using the ISP that came with BLTouch.

Very modifications are needed, or you can just put the stock config file from pre-configurations that marlin offer to your printer model and go that way, but still need to configure bltouch.
I recommend you to go line by line, read and understand what it does and activate what you need/want under configuration.h and configuration_adv.h
It's something to take your time, go slow and make sure it's all right.
About bootloader first try uploading a firmware, i think new models already have bootloader in.

superm1, 2020-03-13:
OK thanks for all your advice :)

sn4k3, 2020-03-13:
You can find your machine configurations here: https://github.com/MarlinFirmware/Marlin/tree/2.0.x/config

Download Marlin
Put your machine configurations there
Start look and editing

shnee, 2020-03-24:
I am also seeing this behavior.

This part of the end code:
```
{if layer_z < max_print_height}G1 Z{z_offset+min(layer_z+30, max_print_height)}{endif}
```
gets evaluated to
```
G1 Z{z_offset+min(layer_z+30, max_print_height)}{endif}
```
in my gcode.

sn4k3, 2020-03-24:
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

Update for the latest PrusaSlicer v2.2 and update profiles from last master

shnee, 2020-03-24:
You are correct, updating PrusaSlicer fixed this issue.

Thank you for your quick response and your work here. Your profiles have significantly improved the quality of my prints.

Closed 2020-03-13.

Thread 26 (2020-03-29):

The best profile.

burnham, 2020-03-29:
Hi my friend,

First of all I want to congratulate you on your excellent work, it has been super useful.

Ok, I just want to make a question.

I have an Ender-3 printer with:

- [Metal V6 Hotend Bowen](https://es.aliexpress.com/item/32844028127.html?spm=a2g0s.9042311.0.0.274263c0qk4atK) with **Nozzle 0,4**

- [Bowden Extruder BMG](https://www.aliexpress.com/item/32917029058.html?spm=a2g0s.9042311.0.0.274263c0Rg10Wo)

- [3D TOUCH](https://www.aliexpress.com/item/32832887426.html?spm=a2g0s.9042311.0.0.274263c0Rg10Wo)

- [Printer board MKS Gen L](https://www.aliexpress.com/item/32802151924.html?spm=a2g0s.9042311.0.0.274263c0Rg10Wo)

- [MKS TMC2208 2208 Stepper Motor Driver](https://www.aliexpress.com/item/32888980385.html?spm=a2g0s.9042311.0.0.274263c0Rg10Wo)

Which profile should I use?

At the moment I use this configuration, but I have so many strings.

Thanks in advance.

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

sn4k3, 2020-03-29:
Hello, you are absolutely using the wrongest profile. You must use Creality Ender-3 Stock + BLTouch for yor setup.

burnham, 2020-03-30:
Thank you for you quick answer, you said "Note that title says 0.6 Nozzle, and you are using 0.4 Nozzle", in the picture says "0.6" but I just change 0.6 to 0.4 in the configuration in the profile I was using.
I will use  Creality Ender-3 Stock + BLTouch for my setup, but my question is, have this configuration any thing to do when I also use Bowden Extruder BMG?

Thanks.

burnham, 2020-03-30:
Ok, just try with your tips "Creality Ender-3 Stock + BLTouch" and I wanted to make a [retraction test](https://www.thingiverse.com/thing:2766430) but my printer start to turn crazy, it starts ejecting filament at high speed.

sn4k3, 2020-03-30:
> Ok, just try with your tips "Creality Ender-3 Stock + BLTouch" and I wanted to make a [retraction test](https://www.thingiverse.com/thing:2766430) but my printer start to turn crazy, it starts ejecting filament at high speed.

Did, you tune your e-steps when change the extruder? If you manual extrude 100mm it does really output 100mm?
You also have changed the firmware right, marlin?

burnham, 2020-03-31:
Asking your question I can print normally when I use CURA, and also I have controlled those 100 mm, I have changed the firmware too and I use the last version of PrusaSlicer 2.2, I did not really have problems with your other profiles except the many strings. I will try again and I will let you know.

Any way I would like to be in contact with you and let you know my experiences.

sn4k3, 2020-03-31:
I have reviewd the profile and i can't find anything wrong. Do you have LA enabled on firmware? If yes try disable it or you must find and tune the value for each filament

burnham, 2020-04-01:
What is the meaning of LA?

sn4k3, 2020-04-01:
> What is the meaning of LA?

Linear Advance --> https://marlinfw.org/docs/features/lin_advance.html

burnham, 2020-04-01:
I think that I know whats is happening.
I just try to print again this [retraction test](https://www.thingiverse.com/thing:2766430) with this configuration
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
As you can see everything seems to be correct in the configuration, then I try to print with the next result (I can not add video in github)
[Video with the process](https://anonfile.com/taa1hcl6oe/20200401_205031_mp4)

After that I did it correctly with CURA, the I start to make a research and I made a clean PrusaSlicer installation with your profiles and I noticed that "Creality Ender-3 Stock + BLTouch" has not PLA profile, I think is where the problem come as you can see in the next pic:

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

Thanks for your support.

sn4k3, 2020-04-01:
Yes i remove them because they are exactly same as prusa so as now new version include them i have removed to prevent duplicates. Click where it say Add/retirar filamentos and search and tick all filaments you want to appear

sn4k3, 2020-04-01:
I just updated the profile, try with it test and reply back

burnham, 2020-04-02:
>
>
> I just updated the profile, try with it test and reply back

Sorry, I was to busy with the family, I will test it tomorrow in the morning and I will let you know.

burnham, 2020-04-02:
I just did what you recommended me, the results are pretty good.
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
 I still have some strings but seems to be good.
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

Really nice.

sn4k3, 2020-04-02:
Ok, don't forget, different colors and filament types will have different results, it's impossible to have a fixed retraction value for every case. Also the result you are getting is pretty good. Stringing will always be present

Closed 2020-04-02.

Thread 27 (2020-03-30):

Quick question about which profile to use

NovaViper, 2020-03-30:
Hi! I just recently started using a 0.8 nozzle on my Ender 3. I'm wondering which profiles I should use for my current setup:

- I have a TriangleLabs V6 Non-Volcano with an Aimsoar BMG clone equipped in a direct drive setup, using [this particular mount](https://www.thingiverse.com/thing:3721746). I also have a pancake motor and guineue BLTouch too

Any recommendations on which profile to choose and how to set it up?

sn4k3, 2020-03-30:
Hi, 0.8mm nozzle without volcano don't bring any benefits other than vase mode with big heights. A 0.6mm nozzle with V6 give you more detail window at same finish speed. With 0.8mm get ready for slow print moves. As you can see i don't have a profile for that setup just because is not worth, but if you want i can build one. Even 0.6mm nozzle can hit volcano limit if you use my boosted profile.

None of the profiles will work without proper configuration first, do you want i made that bundle?

NovaViper, 2020-03-30:
With a 0.6 nozzle, can I achieve the same layer heights/reduced print times? I've got a couple of parts that will take at least 2 and half hours to print with a 0.4 nozzle, but with a 0.8 it cut down the time by 1 and a half hour merely because of the massive layer heights. Hence is why I opted for a 0.8 nozzle instead.

sn4k3, 2020-03-30:
> With a 0.6 nozzle, can I achieve the same layer heights/reduced print times? I've got a couple of parts that will take at least 2 and half hours to print with a 0.4 nozzle, but with a 0.8 it cut down the time by 1 and a half hour merely because of the massive layer heights. Hence is why I opted for a 0.8 nozzle instead.

Not same layer heights, only up to 0.45mm height.

Pratical example:
0.45mm layer with 0.6mm nozzle your max speed must be lower than 35mm/s == 10mm^3/s
0.45mm layer with 0.8mm nozzle your max speed must be lower than 27mm/s == 10mm^3/s

So as you can see 0.6mm nozzle can finish the print at same time as 0.8mm nozzle by tunning speed.
Even with 0.4mm i can boost your extrusion and spare a ton of print time.
Please consider volcano, it worth even for 0.4mm nozzle, but for larger sizes are a must.

Now if you don't need the extra detail from a 0.6mm nozzle, then theres no bad in use a 0.8mm, the down side is you will never able to print lines lower than 0.8mm width.

0.4mm nozzle window (0.4mm-0.7mm)
0.6mm nozzle window (0.6mm-1.2mm)
0.8mm nozzle window (0.8mm-1.7mm)

I have to go sleep now, but tell me if you want keep with 0.8mm and i'll make a configuration tomorrow so you can test, and yes it will give you a speed boost over 0.4mm nozzle

sn4k3, 2020-03-30:
Before i go i just released a pre setup that you can use. Get last master and test with the new printer profile.
Get ready to see your printer very slow moving, but actual printing faster

NovaViper, 2020-03-30:
Cool, thansk! I don't mind switching to the 0.6 nozzle and yeah, I do notice it moves considerably much slower and I lost a bit of accuracy since switching to the 0.8 nozzle. Ok so, if I go with the 0.6 nozzle, what's the maximum possible speeds I can go with, for say with PETG?

sn4k3, 2020-03-30:
Speed (mm/s) doesn't matter,  Volumetric flow is what count and messured as mm^3/s. For v6 and PETG i recommend a maximum of 8mm^3/s.
You can get the volumetric speed with that formula: Layer Height * Extrusion Width * Speed

So, example:
0.30mm layer * 0.65mm extrusion * 41mm/s = 8mm^3/s --> So your max speed for that setting combo should be 41mm/s

NovaViper, 2020-03-30:
Ah ok. So in that case, i'll switch over to the 0.6 nozzle. Er, do you have a profile you recommend me starting off from?

sn4k3, 2020-03-30:
I don't have any, but good news, you can use the Original Prusa MK3 0.6mm nozzle.
You just need to copy printer and change bed size, height and introduce bltouch code.
I can also publish a bundle

NovaViper, 2020-03-30:
Ah cool! Thanks!

NovaViper, 2020-03-30:
Oh question, so would I use the MK3 profile from Prusa or the one that you have in your bundle?

sn4k3, 2020-03-30:
Any will do, i just uploaded your config, please update

NovaViper, 2020-03-31:
Hey uh, the 0.6 profile that you made seemed to have doubled the print time. It used to take about 12 minutes to print a 20x20 hollow calibration cube when using the 0.4mm nozzle @ 0.32 layer height, now it takes 30 minutes using the 0.45 layer height

NovaViper, 2020-03-31:
*Oof*! I just realized I was looking at my print estimator on Octoprint (and it was WAY off). The print time seems to be right about the same

sn4k3, 2020-03-31:
> _Oof_! I just realized I was looking at my print estimator on Octoprint (and it was WAY off). The print time seems to be right about the same

Always compare with PrusaSlicer estimator.
The 0.6mm noozle have 2x fastter results compared with 0.4mm at 0.32mm.
The problem is you printing a small object (20x20), auto speed and cooling will come in play and slow down your print, so thats normal to be the same. You also have the small perimeters which will cut speed so keep in mind that 20x20 is not a good test, you will only notice the diference on real prints

NovaViper, 2020-04-06:
Hey, I've been trying to setup the 0.6 profile you made but I noticed there are several profiles missing, like, there's no 0.2 or anything below 0.3. And there's a couple of materials missing too (TPU and PLA specifically)

sn4k3, 2020-04-06:
> Hey, I've been trying to setup the 0.6 profile you made but I noticed there are several profiles missing, like, there's no 0.2 or anything below 0.3. And there's a couple of materials missing too (TPU and PLA specifically)

I have added now the missing profiles.
About filaments read https://github.com/sn4k3/Ender3/issues/26#issuecomment-607474282 OR readme point 2)

roomme13, 2020-04-21:
Hi, BMG extruder in remote setup not called as and direct drive right? It should same as BMG as directdrive but with small tube to the heatsink? Or it's different?

Rollback from direct volcano to stock ender3 with remote BMG, as every time I  print  the volcano clogged.  The funny thing is when print starts the nozzle clogged, when I stop and try  extrude manual, it work normally, even the first stroke before print is in good visual. Frustrating about this and roll back to stock ender hotend.

sn4k3, 2020-04-21:
Right, what ever you use in remote setup is always bowden. Direct Drive is where you have your extruder gears just close to hotend as possible.

The clog might be another problem, you need troubleshoot first before give up.
Is V6 heatsink + volcano?

roomme13, 2020-04-21:
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

So stock printer profile should be fine if i use bmg as remote drive?

I think so, at the first I thought it retraction problem, but even I make it 0.5mm, still clogged.

Yes it's V6 heatsink with Volcano, 4020 fan heatsink.
The clogged always happen in heatblock part of heartbreak.

sn4k3, 2020-04-21:
Yes you should use the stock profile if using 0.4mm nozzle and bowden

So i would strict follow e3d instalation guide, heatbreak must be tight agaisnt nozzle at correct height. If extrude by hand works fine, then it can be antoher thing, like LA, if you have it enable on marlin, just disable it
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
sn4k3, 2020-05-09:
Hello, at this point i don't recomend BMG,  go Hemera instead as BMG still have a long path from guears to extruder. I use skelestruder at my ender 3 because of that, very short path. But now you have Hemera to go with... BMG is same price if you go orginal, of course clones are cheap. So if you have the money don't look back and pick hemera.
About block always go All Metal! PTFE will disallow higher temperatures such for ABS and higher, doing so can kill you in a mid/long time.
My recommendation: Hemera + Platted Copper Volcano + Platted Copper Nozzle + Titanium Heatbreak

gminadak, 2020-05-09:
I'm using only cloned parts on my printer ;).
Hemera looks the perfect combination to go this days but its way above the money i'm willing to spend for my ender.
The Skelestruder looks like beast! and i like it, i will search for more information on this setup.
Thank you for the quick reply.

sn4k3, 2020-05-09:
I dont know if they already cloned hemera, maybe yes but under other name? Well you can always go with what you already have. BMG make sure to use a design that clamps heatsink directly to avoid a longer path.
Skelestruder works very well, and while almost part free you need to print many parts, not easy for start but it get better as you start assemble. I recommend you have another printer just in case of any part failure

gminadak, 2020-05-09:
The reason i'm considering to upgrade to volcano is to solve the problem with this lines, i have try everything but even with the "direct drive" the problem is there.

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

sn4k3, 2020-05-09:
That doesn't seen a extruder problem... Part of your problem may be  the poor Z.
Best thing you can do is upgrade to dual Z and give it proprer care.
Also check your belts, check your wheels nuts every wheel must rotate and grab the frame. With your hand try to stop a wheel while its moving, it is hard to stop its ok, otherwise if you easy stop then just with a touch mean they need a bit more tight

sn4k3, 2020-05-09:
Here a mod for super strong dual Z: https://www.thingiverse.com/thing:3612465

gminadak, 2020-05-09:
The Z was the first thing i had in mind so i printed this test from dpetsel and the problem is almost gone.
The big part is with seam aligned on back the other in VASE mode.

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

sn4k3, 2020-05-09:
The lines are still there, some are more squish then others, trust me tune your Z is the weak point of ender3

gminadak, 2020-05-09:
Thank you for your help i will recheck my Z and wheels

sn4k3, 2020-05-09:
for example, move your Z just 1m up other down other up other down, and check if right side move or stay still.

gminadak, 2020-05-10:
I did check my wheels and X the X is aligned with the top and my Z extrusions have the same length.
What i did and i see some improvement was to hand tighten the lead screw nut bolts and then turn back approximately one turn.
The problem is still there but less noticeable.
I have observe the right side of the X gantry and i see the movement by hand and when the printer running with the Z hop.
I had over tighten the Wheels on this side and it was like losing some movement now seems better and that reflects to prints but still not perfect i can also move the right side by hand a little.
I think i need to add a second Z gladly i already have the motor from the stock extruder.
Your dual Z setup looks nice but what filles i need to print and do i need MGN linear rails for this mod?
Thank you.

sn4k3, 2020-05-11:
Lack of dual Z is the worst problem on all enders

gminadak, 2020-06-13:
Hello @sn4k3 how are you?
So after many prints and playing with he settings
I have discover a new problem when i try to print something cylindrical there is no way to complete hide the seam i have try random, aligned, nearest but nothing works is this the way it should be?

Below is a picture of the prints and my configs if you want to take a look
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

[slicer.zip](https://github.com/sn4k3/Ender3/files/4774833/slicer.zip)

Thank you.

sn4k3, 2020-06-13:
Hi, see this anwser: https://forum.prusaprinters.org/forum/prusaslicer/prusa-slicer-2-0-how-would-i-go-about-to-get-rid-of-that-vertical-seam/

Your best bet is tune your printer and if in use of LA get the best K factor.
Cylindrical shapes are  the worst

gminadak, 2020-06-13:
I did check my e steps again and it was off by 1.4mm looks better now but still visible.
Thank you for your help.

Closed 2020-06-13.

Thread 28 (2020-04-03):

Issue with install on mac using Prusaslicer 2.2.0+

juan9999, 2020-04-03:
Thanks so much for your work on this!

If I go through the config, and select the beta creality driver, and I exit, then copy the required files, I get an error on startup.

I worked around it by deleting/reinstall and choosing a MK3 printer and creality beta (and removing MK3 later) and it works (plus I get the ender logo on the bed). I then select your printer configurations.

Unfortunately, despite doing that, most of your filaments do not appear (only 4 do).

Any tips?

Thanks!

sn4k3, 2020-04-03:
Hi, read this: https://github.com/sn4k3/Ender3/issues/26#issuecomment-607474282

Closed 2020-04-21.

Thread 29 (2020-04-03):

Profiles not loaded by slic3r

Venice-89, 2020-04-03:
Hi,

I am using your Slic3r for a while. Many thanks for your great work !

Now I made an updates of your Profiles on my existing slic3r 2.1 but your profiles doesn't appear in the drop down menue, only the printer profiles, not the print or filament profiles.

I tried to delet everything and started from scratch but no luck.
Then I updated to Slic3r 2.2 and but with the same problem :/

Do you know what the problem could be?

sn4k3, 2020-04-03:
Hi, do you strict follow the instalation guide from readme at project page?
Also for filaments  please read this: https://github.com/sn4k3/Ender3/issues/26#issuecomment-607474282

Venice-89, 2020-04-03:
Hi,

yes absolute, I followed the instruction but only the printers are added to the dopdown menue.
But it's possible to load the profile via import mhhh

I will try it on other notebook again

sn4k3, 2020-04-03:
Can you attach a printscreen of the slicer and dropdowns?

Darisson1, 2020-04-11:
Unfortunately I have the same Problem. I will reinstall everything tomorrow and I will make Screenshots.
Maybe you can help me and we can solve the Problem.
Thank you !

sn4k3, 2020-04-11:
Please strict follow the readme

karasu, 2020-04-20:
Hi,

To be able to select the profiles I had to change this line:
```
compatible_printers_condition = printer_notes=~/.*PRINTER_VENDOR_CREALITY.*/ and printer_notes=~/.*PRINTER_MODEL_ENDER3.*/ and nozzle_diameter[0]==0.4 and printer_notes=~/.*PRINTER_NOT_VOLCANO.*/
```
to this:
```
compatible_printers_condition = printer_model=="ENDER3" and nozzle_diameter[0]==0.4
```
hope this helps.

sn4k3, 2020-04-20:
> PRINTER_VENDOR_CREALITY

Strange, can you confirm under Printer -> Notes if you have the following lines:

PRINTER_VENDOR_CREALITY
PRINTER_MODEL_ENDER3
PRINTER_NOT_VOLCANO

?

karasu, 2020-04-20:
Hi,
I have exactly this:
```
Don't remove the following keywords! These keywords are used in the "compatible printer" condition of the print and filament profiles to link the particular print and filament profiles to this printer profile.
PRINTER_VENDOR_CREALITY
PRINTER_MODEL_ENDER3
```
I think the problem is that the new printers didn't show up after being copied (or I didn't see them, let me test it again as it's the first time I'm using PrusaSlicer).

sn4k3, 2020-04-20:
Theres one line missing, what profile you using?

karasu, 2020-04-20:
Creality ENDER-3

sn4k3, 2020-04-20:
Thats strange, it works for me... Maybe you installing profiles on wrong folder? Since i don't own linux i cant confirm, but works under windows

karasu, 2020-04-20:
No, no... it's the .PrusaSlicer folder, I'm sure.

With the latest version 2.2.0 the Ender-3 printer profile does not have that "PRINTER_NOT_VOLCANO" by default.

Maybe you could update your README with something like "if the profiles do not show up, just add PRINTER_NOT_VOLCANO to printer->notes"...

Anyway, thanks for sharing your work!

sn4k3, 2020-04-20:
The Creality ENDER-3 printer is not my profile, is the original from prusa, so its normal that doesn't include the note. I will try see what's happening...

karasu, 2020-04-20:
I see. The problem is that after copying your files the new printers do not
show up.

I'm going to sleep now, but tomorrow I'll try it again with a clean
install, just in case I'm doing something wrong.

El dl., 20 abr. 2020, 22.22, Tiago Conceição <notifications@github.com> va
escriure:

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

karasu, 2020-04-21:
I'm really sorry. I've tried again today in a clean installation and it's working now. Maybe I was doing something wrong and I didn't realize.

Thanks for your help!

sn4k3, 2020-04-21:
Seens fixed

@karasu
"I'm really sorry. I've tried again today in a clean installation and it's working now. Maybe I was doing something wrong and I didn't realize.
Thanks for your help!"

Closed 2020-04-21.

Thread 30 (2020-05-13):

[QUESTION] Print quality in Overhangs

Astrofreak85, 2020-05-13:
With your profiles, when I reduce the max extrusion to 50mm/s I get good results, else my extruder sometimes skipped.
But I have a problem with overhangs, like the front of Benchy. The layers thee alway curl ob while being printed. When I slice Benchy with Cura, and stock settings it looks good...
What is causing the problem?

Astrofreak85, 2020-05-13:
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

sn4k3, 2020-05-13:
Need more information, such as:
Is ender stock or modded?
Filament used
Temperature used
printer profile + print used

Astrofreak85, 2020-05-13:
Ender 3 pro
Not modded, just Metal Extruder an other cooling.
Filament, PLA from "Das Filament" 210°C
Profile: yours Ender 3 stock, Print speed is yours, not change for the print above

currently I am putting a print with same speed settings as used in Cura

When I compare Cura and Prusa print after the main deck of benchy is ready, it seems prusa uses much thicker walls...

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

Astrofreak85, 2020-05-13:
The additional fill between the two outher perimeters seems to corelate with number of upper an lower layers in PrusaSlicer, at least changing this has an effect here, wenn i reduce upper and lower to 3 ist gone, and the print looks better, but still not perfect
strange how different the slicers behave...
maybe this has nothing to do with your profiles at all...

sn4k3, 2020-05-13:
Diferent software have different planers and ways of print, it look like a overhang problem. You can try reduce overhang speed (bridge) and increase cooling fan speed on those cases which for PLA is always 100%.
Also make sure you use latest prusaslicer + my profiles
You can try set every setting equal to CURA and see if problem stays or not. I printed a bench two days ago with PLA and i don't have that problem, i'm using 0.65mm lines and 0.6mm nozzle which is worst for overhangs (more mass)

Closed 2020-06-13.

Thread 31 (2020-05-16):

getting files into slicer

lumpy1965, 2020-05-16:
i have copied the files across to the correct subfolders ("printer", "filament", "print") in windows, C:\Users\XXXXX\AppData\Roaming\PrusaSlicer but they don't show up in the drop down box in the program. what am i doing wrong?

sn4k3, 2020-05-16:
Have you followed instructions? You need do exactly what is told on readme

lumpy1965, 2020-05-17:
yes i was, 3 or 4 times.
ended up uninstalling Prusa and purging the registry, re-installing from scratch, then tried copying the folders again.
all good now
thanks

Closed 2020-05-17.

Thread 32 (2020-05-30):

[QUESTION] Why no 0.4 nozzle profile for Direct Drive?

MiniNinja1, 2020-05-30:
I'm curious why you don't have profiles for a direct drive with a 0.4 nozzle. It's a common nozzle size.

I already made one myself based on some of your settings and it's been printing fine. I just wanna know your thoughts!

sn4k3, 2020-05-30:
Most of profiles were made based on my usages or on requests.
Do a 0.4mm nozzle for DD is very easy, just copy stock profile and change retraction

MiniNinja1, 2020-05-30:
How about other nozzle sizes besides the one you've given? Do I simply change _Nozzle diameter_ and _Max/Min Layer height limits_?

sn4k3, 2020-05-30:
If i have that nozzle size configured and you just want convert Bowden to DD then Yes.
If not and let's say you want configure a 0.5mm nozzle, then no and you need to create each print profile with correct extrusion widths and calculate max speeds given the set extrusion

MiniNinja1, 2020-05-30:
Okay, I see what you mean. I think I'll stick with my 0.4 nozzle for now and do the necessary adjustments. Thanks!

o5, 2020-10-30:
I've upgraded my Ender 3 PRO by this [guide](https://www.3dpedie.cz/en/inspirations/octoender_by_kiron). I used your profile for stock Ender before but now I'm looking for DD with 0.4mm Nozle and P.I.N.D.A. I started a new profile based on your DD 0.6mm Nozle (no Volcano). Any tips from you? :)

I changed: Max print height, Commented out G-CODE for BLTouch, Nozzle diameter, Set Retraction length to 1.5mm and speed to 120mm/s.

I can prepare PR if you are open to add a new profile.

sn4k3, 2020-10-30:
Direct drive with 0.4mm nozzle you can clone stock ender bltouch and change the the Retraction length and speed, everything will be the same, also adapt the start gcode for the probe that you are using.
Remove PRINTER_HAS_BOWDEN and add PRINTER_HAS_DIRECT_DRIVE on printer notes.
As addition if you are using linear advance, set a model ex: PRINTER_FULLMODEL_ENDER3_DD_04

Closed 2020-06-13.

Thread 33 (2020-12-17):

[QUESTION] There is no stock 0.4 nozzle "print" profile

rufik, 2020-12-17:
Do I see right there is no "print settings" profile for stock 0.4 nozzle?

sn4k3, 2020-12-17:
There are, are you with any beta PrusaSlicer version?

rufik, 2020-12-18:
I'm using PrusaSlicer 2.2.0, so no bete here. When I go into `PrusaSlicer/print` folder there are print profiles for 0.40 nozzle like that:
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

Which one is for stock hotend? I can see only for MK3 Volcano ones...

pahowes, 2020-12-18:
If you're looking in the `PrusaSlicer/print` folder under your user profile, you'll see only those you added manually. The first number is the layer height, not the nozzle size. The second number `0.6 nozzle MK3 Volcano` would refer to an E3D Volcano hot-end with a 0.6 mm nozzle.

The factory profiles are found in the application directory as `profiles/PrusaResearch.ini`. They're all lumped together in that file.

sn4k3, 2020-12-18:
https://github.com/sn4k3/Ender3/tree/master/PrusaSlicer/print

Stock nozzle files ends with: Ender3.ini

Closed 2021-04-21.

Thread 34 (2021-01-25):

[QUESTION] No PLA filaments show compatible for stock Ender 3?

jwvanderbeck, 2021-01-25:
Starting from scratch, I installed the latest PrusaSlicer and launched it.  In the configuration wizard I selected a bunch of PLA filament profiles, just basic ones like AmazonBasics, Hatchbox, eSiun, etc.  Next I copied the profiles for this project over and re-launched.

When selecting the Ender 3 Stock none of the PLA filaments will be available, as they all are seen as incompatible.

sn4k3, 2021-01-25:
Yes, they now have filaments per brand, so that are only for prusa and require flags on printer like PRINTER_VENDOR_PRUSA3D and model mk3 defined.
Just clone my generics and tune from there, or select prusa mk3 clone filament you want and remove conditions to open to all printers

Closed 2021-04-21.

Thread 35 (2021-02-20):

[BUG] Settings not working for PrusaSlicer 2.3

tb205gti, 2021-02-20:
**Describe the bug**
The settings does not show up when using PrusaSlicer 2.3

**To Reproduce**
Steps to reproduce the behavior:
install latest PrusaSlicer (2.3) - copy the profile files over - prusa shows the following message when starting Prusaslicer:

"You have the following presets with saved options for "Print Host upload":
    "Creality Ender-3 DirectDrive Volcano 0.6 Nozzle + BLTouch",
    "Creality Ender-3 DirectDrive Volcano 0.6 Nozzle + BLTouch RECALL",
    "Creality Ender-3 Volcano 0.8 Nozzle",
    "Creality Ender-3 Volcano 0.8 Nozzle + BLTouch",
    "Creality Ender-3 Volcano 0.8 Nozzle + BLTouch RECALL",
    "Original Prusa i3 MK3 0.6 nozzle Volcano",
    "Original Prusa i3 MK3 0.6 nozzle Volcano NO PINDA"

But since this version of PrusaSlicer we don't show this information in Printer Settings anymore.
Settings will be available in physical printers settings.

By default new Printer devices will be named as "Printer N" during its creation.
Note: This name can be changed later from the physical printers settings"

**Expected behavior**
Expect it to have the profiles as on 2.2

**Screenshots**

**Desktop (please complete the following information):**
 - OS: MacOS Catalina
 - Version 10.15.7

**Additional context**
Add any other context about the problem here.

sn4k3, 2021-02-20:
Yes, i have to fix them for new version, also i need to update the new fields that was introduced

nurglexp, 2021-04-17:
I get great results using your profiles in 2.2, really looking forward to new profiles for 2.3. Will you be releasing updated versions soon?

sn4k3, 2021-04-17:
> I get great results using your profiles in 2.2, really looking forward to new profiles for 2.3. Will you be releasing updated versions soon?

I can upgrade them yes, but now prusaslicer have official profiles for ender3 and others, did you try them?

nurglexp, 2021-04-17:
I didn't want to upgrade to 2.3 as I saw your profiles didn't work. I had such good prints using your profiles I stuck with 2.2 but there are some features of 2.3 that interest me. If you think the inbuilt profiles with 2.3 are good i'll give them a go.

sn4k3, 2021-04-17:
My profiles will work with 2.3, only the new fields will have some different default values. But yeah you can try the official ones, if you find them worst tell me back and i will make a push

nurglexp, 2021-04-21:
I've tried the inbuilt creality profiles in version 2.3.1
They seem ok, I'd still prefer to use your profiles if you have time to push an update.
Many thanks!

sn4k3, 2021-04-21:
You use the stock profile or other?

Closed 2021-04-21.

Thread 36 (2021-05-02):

[QUESTION] Direct Drive for 0.4 Nozzle profile

NovaViper, 2021-05-02:
Hey, I'm wondering if you could make a profile for 0.4 nozzles with direct drive

sn4k3, 2021-05-02:
It's easy to do:

1. Clone "Creality Ender-3 Stock" profile
2. Change retraction settings to:
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

NovaViper, 2021-05-02:
Ah cool. Thanks for the info! Uh... how do I go and get the filament profiles for the machine?

sn4k3, 2021-05-02:
You can get them from Official creality filaments on PrusaSlicer, you just need to go to PrusaSlicer Wizard and select Ender3 Printer and it filaments and i think it will show up

NovaViper, 2021-05-03:
Ah ok, thanks!

Moxie1776, 2021-05-03:
Be careful with those settings, sometimes with length that hi it can cause your hotend to clog. Speed can be adjusted up too, I would play with those settings. You may want to try zlift starting at .2.

sn4k3, 2021-05-03:
0.8mm is not that high. My settings are for 3ed setup similar to prusa, but of course there are no universal setting, adjust if needed

Moxie1776, 2021-05-04:
> 0.8mm is not that high. My settings are for v6 e3d setup similar to prusa, but of course there are no universal setting, adjust if needed

If I go past .6 my all metal microswiss clogs...

NovaViper, 2021-05-05:
> > 0.8mm is not that high. My settings are for v6 e3d setup similar to prusa, but of course there are no universal setting, adjust if needed
>
> If I go past .6 my all metal microswiss clogs...

I actually have a V6 and BMG (both are clones) setup with the BMG directly connected to the V6 and dual 5015 fans. The retraction length and speed is actually pretty normal for a V6, anything above 1mm is too much.

Closed 2021-05-03.

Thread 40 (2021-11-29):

[QUESTION] I want to use BLTouch in the ender3V2 in Klipper , but i don't know the pin number.

2718564960, 2021-11-29:
I want to use BLTouch in the ender3V2 in Klipper , but i don't know the pin number.
This is the picture, thank you .
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

plazmax, 2021-11-29:
i think u asked wrong repo this is for prusa slicer ender 3 profiles, but u can check theese:

https://youtu.be/sWKLxxFEEbc?t=497
https://www.klipper3d.org/BLTouch.html

https://www.smith3d.com/ender-3-v2-bltouch-firmware-installation-guide-by-smith3d-com/
https://github.com/Klipper3d/klipper/blob/master/config/printer-creality-ender3-v2-2020.cfg
https://all3dp.com/2/klipper-ender-3-v2/#i-9-changes-for-a-bltouch-sensor

2718564960, 2021-11-29:
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

sorry, thank you !

Closed 2021-11-29.

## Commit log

2018-08-21 Volcano 0.8mm nozzle
2018-08-21 Extruder gear
2018-08-21 Belt Tensioner
2018-08-21 Volcano Nozzles
2018-08-21 XT30 connectors
2018-08-23 Added BLTouch board adaptor
2018-12-16 Improve ABS auto cooling and add test objects
    [1Layer20x20.stl, 1Layer60x60.stl, 2Layer20x20.stl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]
2018-12-16 Add more profiles and 0.6mm Nozzle with direct drive
2019-05-23 More print profiles for 0.6mm nozzle volcano
    * Added more profiles for 0.6mm nozzle volcano
    * Modified filaments
    * Changed to PrusaSlicer
    * Tuned some parameters
2019-05-24 Added more profiles to 0.6mm nozzle Volcano
2019-06-04 Enable LA, set your own value on filament tab
2019-10-14 Add ender3 bed to slicer
2019-10-14 Added macOS instructions to user the Ender3 model .stl
2019-10-16 Added a alternative ender3 model cut at bed height
2019-12-21 Fixed accelaration values for old profiles and filaments
    - Fixed accelaration values for old profiles
    - Add new filament features
    - Add new filament
    - Add lithophane profile for 0.6mm volcano nozzle
2020-03-30 Added 0.8mm nozzle direct drive (Test)
2020-03-30 0.6mm nozzle DD
2020-04-06 More 0.6 nozzle profiles
